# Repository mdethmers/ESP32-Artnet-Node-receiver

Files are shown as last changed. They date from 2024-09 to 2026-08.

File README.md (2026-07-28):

# ESP32-Artnet-Node-receiver

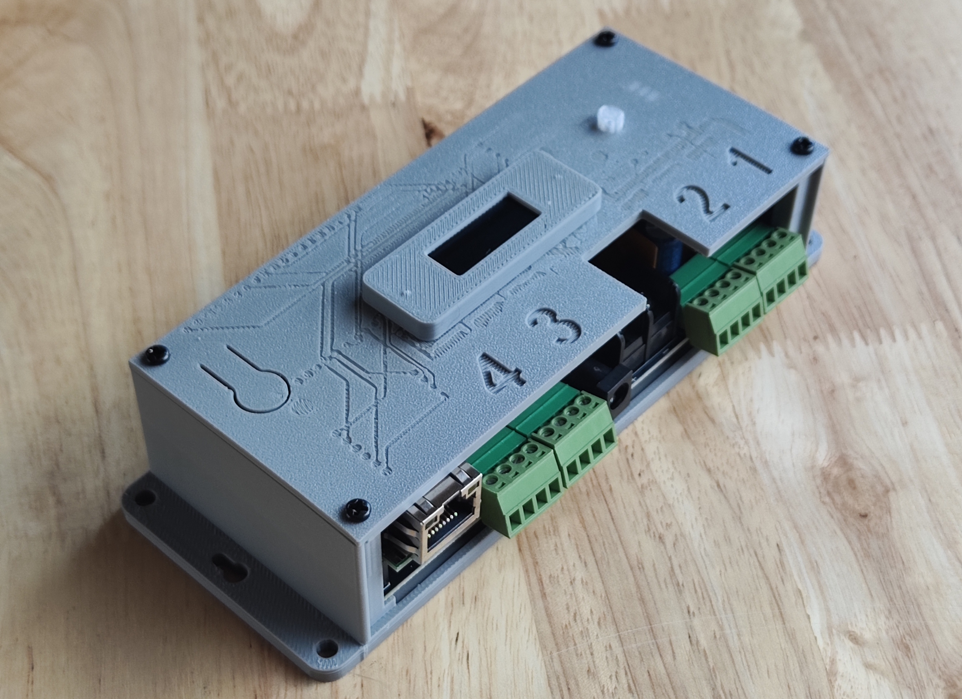
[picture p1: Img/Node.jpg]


This Artnet ESP32 LED controller is a high-performance, open-source solution for controlling addressable LEDs using Ethernet or Wi-Fi. This project allows you to control multiple LED strips using the Artnet protocol via an ESP32 microcontroller with a W5500 Ethernet module or ESP32-ETH01. The code includes a simple web server for configuration and control of the LED strips. For optimal performance, use the W5500 as the ETH01 suffers from performance issues. 

NOW FOR SALE: [https://www.etsy.com/nl/shop/LichtBit](https://lichtbit.etsy.com)

### Videos & Tutorials
Soldering Tutorial: https://www.youtube.com/watch?v=-qxbHJJCwbM

Node & Resolume Arena configuration: https://www.youtube.com/watch?v=1a7sWZTA7lg

## Features

- 4 Outputs, 16 Universes in Total: Supports up to 4 LED strips with 4 universes per output, enabling large-scale LED installations.
- Supports 3 (RGB), 4 (RGBW), and 5 (RGBAW) color order LEDs.
- Supports 3-wire LEDs (WS28xx) and 4-wire  SPI clock-based LEDs (APA102).
- Ethernet and Wi-Fi Support: Supports both wired and wireless Art-Net control for flexible connectivity.
- AP Mode for Debugging: Easily configure the device in standalone mode without needing an external network.
- Static IP option for permanent installations.
- Physical button for Mode switching between artnet, static IP, RGB test and static color.
- Over-The-Air (OTA) updates to update your node with different versions easily.
- Configure the number of LEDs, outputs, start universe, and node name via a web interface.
- High Frame Rates: Over 40 FPS, depending on the software used.
- Reliable Performance: Boasts 99%+ reliability with less than 1% dropped frames.
- 128x32 OLED Display Support: Provides real-time status updates and configuration feedback.
- Status RGB LED: Indicates device status for easy debugging and monitoring.
- **RGB Test Cycle**: Quickly test LED outputs with built-in cycling modes.
- Fully Open-Source: Includes PCB design and BOM, allowing users to build their own cost-effective controllers.

## PCB Design
This is the ongoing PCB design, using 12v-to-5v step-down converters, car fuses for protection and screw terminals for easy connections. 
Project: https://oshwlab.com/matthijsdethmers/artnetnode-esp32
EasyEDA Editor: https://easyeda.com/editor#project_id=86fd5b1121594bfa85fd2c5eed017e20

## Hardware Requirements

- ESP32-Wroom-Dev1 (or ESP32-ETH01 microcontroller)
- W5500 Ethernet module
- LED strips compatible with I2SClockless LED driver (Tested on WS2811, WS2812(B), WS2815)
- 128x32 OLED Display (Optional for visual feedback)
- WS2812 RGB Status LED (Optional for status indication)
- 12v/5v Power Supply

**Important!** Only a few ESP32's are supported! Check the WebServer_ESP32_W5500 for supported Boards when using the W5500.

## Node Pinout
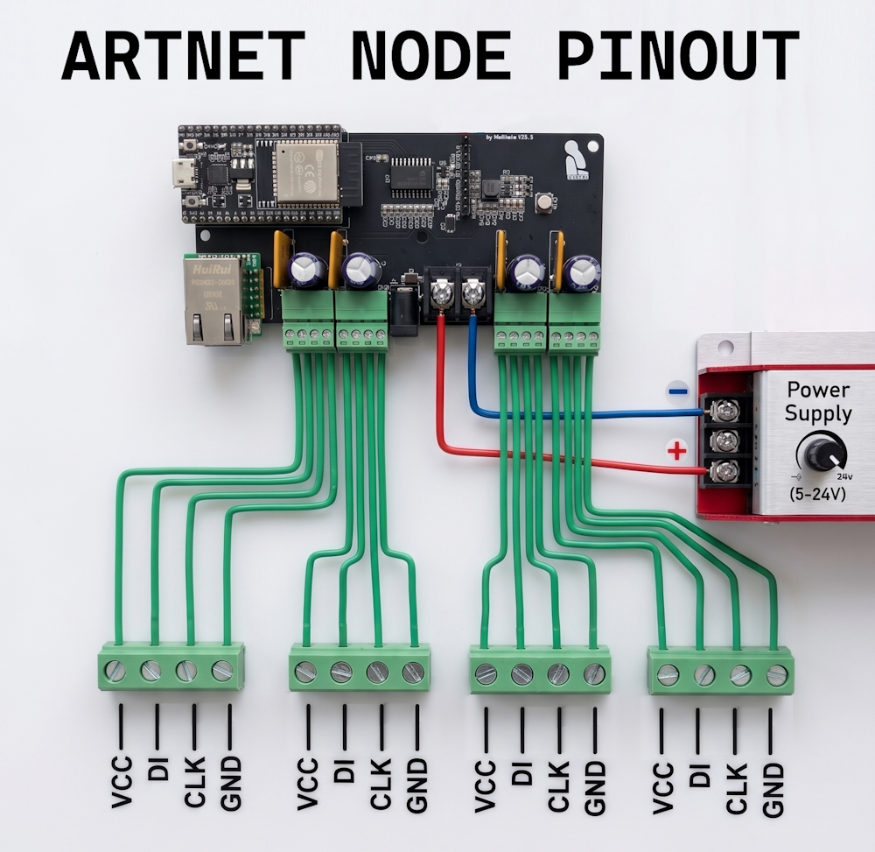
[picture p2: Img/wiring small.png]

  
## Software Requirements

- Arduino IDE with ESP32 support
- Espressif ESP32 board manager library
  - Use https://espressif.github.io/arduino-esp32/package_esp32_index.json
  - Version 2.0.17 or lower, otherwise compilation errors arise
- Libraries:
  - **Preferences** https://www.arduino.cc/reference/en/libraries/preferences/
  - **WebServer_ESP32_W5500** https://github.com/khoih-prog/WebServer_ESP32_W5500
  - **I2SClocklessLedDriver** https://github.com/hpwit/I2SClocklessLedDriver
  - **FORKED artnetESP32V2** https://github.com/mdethmers/artnetesp32v2
  - WebServer.h (For Wi-Fi and web interface support)
  - Adafruit_NeoPixel.h (For addressable LED control)
  - SPI.h, Wire.h (Built-in libraries for communication)
  - Adafruit_GFX.h (Graphics library for OLED)
  - Adafruit_SSD1306.h (OLED display driver)
  - Update.h (OTA updates)
 
## Supported LED ICs
All LEDs based on the wsXXXX and clocked LED series are supported. These can be 3, 4, or 5 channel LEDs. These include, but are not limited to:
  - WS2805, WS2811, WS2812, WS2813, WS2814, WS2815 (Tested)
  - APA102, SK6812 SPI-based LEDs (Tested)
  - SK6812, SK6812W, SK6812-mini (Not tested)
  - GS8208, TM1814, TM1829, UCS8904, UCS8903, FW1906 (Not tested)

## WLED
Check this [youtube video](https://www.youtube.com/watch?v=f3e7oMOB8D4) on how to install WLED!

This controller also supports the WLED software (WIFI ONLY!), supporting Artnet, DMX, and Standalone animations. When using multiple nodes, these can sync over WIFI in standalone mode. Install WLED through the [Web Installer](https://install.wled.me/) (plain version!).
In the WLED folder, you can find a [WLED config file](WLED/wled_cfg.json) that works with the controller, which you can use to receive the correct pin settings. Upload these in the security and update pagae > Restore configuration. This config file is set to 680 LEDs per pin, using a 10A power supply, and with WS2814/SK6912 type leds. CHANGE THESE ACCORDING TO YOUR OWN SETUP!

The W5500 Ethernet module and OLED screen can work with WLED:
- W5500 capable version of WLED is available here and should work (Not tested): https://github.com/stcalica/WLED-W500
- 128x32 OLED 4-line display mod available as well (Not tested): https://mm.kno.wled.ge/usermods/4LineDisplay/#installation_1

### WLED ARTNET / sACN (E1.31)
To get Artnet to work on your WLED install, go to SYNC settings and set your network DMX input to Artnet or sACN (E1.31), and DMX mode to Multi-RGB. Make sure to reboot. 
In LED preferences, set the number of LEDs to the number of universes you need (Eg. 340 for 2 universes per output, maximum I got working was 510 leds / 9 universes). Set resolume to send the number of universes equal to # outputs * # of universes per output. 
# Configuration

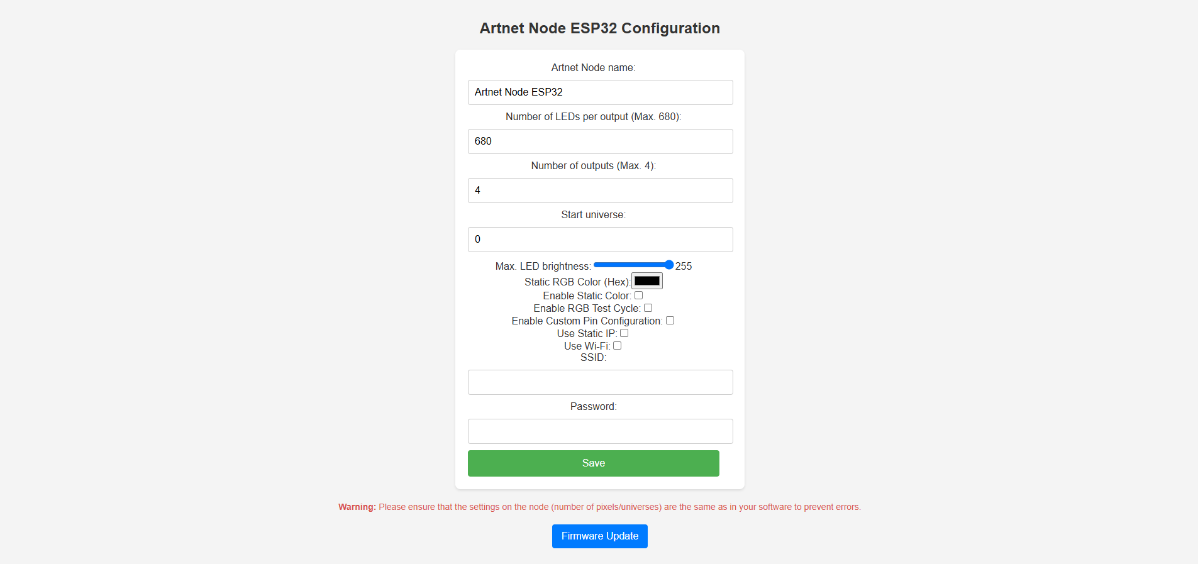
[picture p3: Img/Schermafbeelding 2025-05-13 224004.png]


## Access the Web Interface:
- After uploading the code, connect your ESP32 to a network using the W5500 Ethernet module.
- Set core debug level to "info" for extra information on performance
- Find the IP address assigned to the ESP32 and open it in a web browser.
  - To find the IP address easily, use Resolume's advanced output. It will autodetect the Artnet node.
 
## Mode switching with the Boot button
The code allows you to use the boot button to switch between Ethernet, Wifi, AP, RGB Test cycle, and a static colour. In some of the modes, a long press allows you to change more settings by single pressing. Exit by long-pressing again.  
- Ethernet > Long press > Switch between static IP / DHCP (WORKING!)
- Wifi > Long press > Switch between static IP / DHCP (WORKING!)
- RGB Test cycle > Long press > Switch to other test pattern (Not implemented yet)
- Static colour > Long press > Switch between 10 different colours (WORKING!)

Change this code with your own colours before compiling. 
```
const String presetColors[PRESET_COLORS_COUNT] = {
  "#FF0000", // Red
  "#00FF00", // Green  
  "#0000FF", // Blue
  "#FFFF00", // Yellow
  "#FF00FF", // Magenta
  "#00FFFF", // Cyan
  "#FFFFFF", // White
  "#FF8000", // Orange
  "#8000FF", // Purple
  "#000000"  // Black/Off
};
```
 
## OTA updates
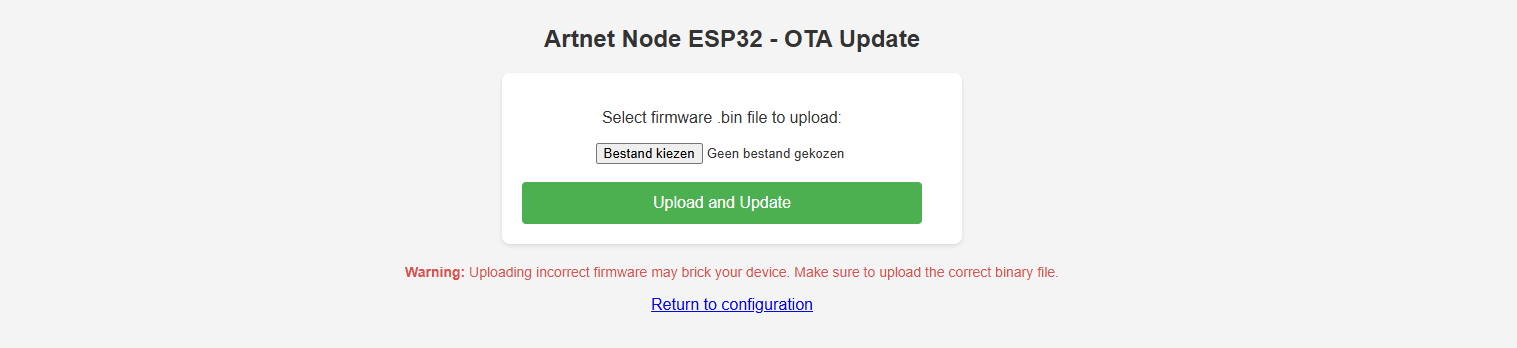
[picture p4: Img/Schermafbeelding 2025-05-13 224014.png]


Upload the BIN file to your Node to have OTA updates. Easy when your node is in a hard to reach or remote place!

## Access the AP mode:
- After 30 seconds without any Ethernet response, an AP mode will automatically launch
- You can use this to connect to the Node and set up settings or a Wifi connection. 

## Configure the LED Controller:
Important! Be sure that the Universes/outputs/leds always match what you output. A mismatch can result in a black output. 

## Pin/Setting/Config info
- Default led strip pins are 12, 14, 27, 26 (more outputs can be added if necessary. Change config accordingly).
- Default status led is set to pin 16.
- SPI-based LED clock line can run from Pin 17. Never versions of the board have this pin connected in the connector. 
- Level shifter OE is set to pin 25 and should be set LOW
- Pin 16/17 can be reprogrammed for new functionality/adding more outputs. (They are connected to the 5v level shifter). 
- I2C pins for OLED are set to pins 21 and 22.
- The default timeout is set to 30 seconds.
- There is a 5V switch Where the 12v regulator sits. Use this if you power the node with 5V instead of 12V! The esp and other logic will be powered from the 5v power supply instead of the 12v to 5v regulator.

To enable outputs, the level shifter should have its OE set to low. OE is connected to IO25, and can be set during setup like this; 
```
void setup() {
  Serial.begin(115200);

  pinMode(ShifterPin, OUTPUT);
  digitalWrite(ShifterPin, LOW);
```

### A note on direct Ethernet connection between Node and PC
Sadly, the W5500 does not support Auto-MDI/MDIX, which means you need a crossover cable whenever you want to connect directly from your PC to the Node with an Ethernet cable!

# Basic resolume setup example
To get you up and running with your node, I provide a basic setup example for Resolume. Other software will work similarly.
1. Connect your node to a router (DHCP) or switch (Static IP) through Ethernet, wifi, or AP mode (192.168.4.1).
2. Once your node is successfully connected to your network, navigate to the configuration page (192.168.1.xxx) and set the Node's Name, Number of outputs, and MAXIMUM Leds you connect to your output.
3. Optional) Enable the RGB test cycle or Static color to test if all outputs and LEDs behave as expected.
4. In Resolume, set the correct network adapter in Preferences>DMX.
5. In Resolume's advanced output, add a new Lumiverse and add the LED strips.
6. In Resolume's advanced output, set the IP address.
7. The node supports 4 universes (680 LEDS) per output. If you need all 16 universes (680 leds per output), add 4 Lumiverse outputs and set the right universes per output. For output 1 that is start universe 0, For output 2 that is start universe 4, For output 3 that is start universe 8, For output 4 that is start universe 12. Change this to the number of universes per output that you need.
8. Your strips should now light up!

## Open-Source Contributions
This project is fully open-source! Feel free to contribute improvements, share your builds, and collaborate with the community.

##License
This project is released under the MIT License. You are free to use, modify, and distribute it with proper attribution.

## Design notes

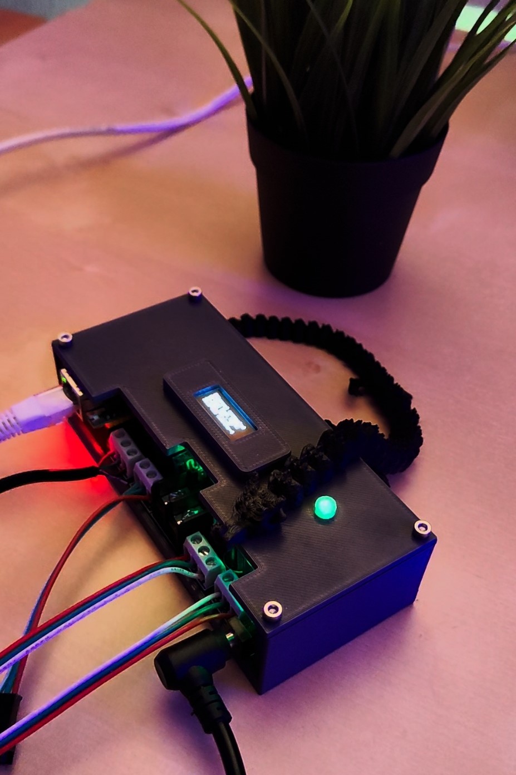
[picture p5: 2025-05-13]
Img/Screenshot_2025-04-18-11-17-45-936_com.miui.mediaviewer[1].jpg

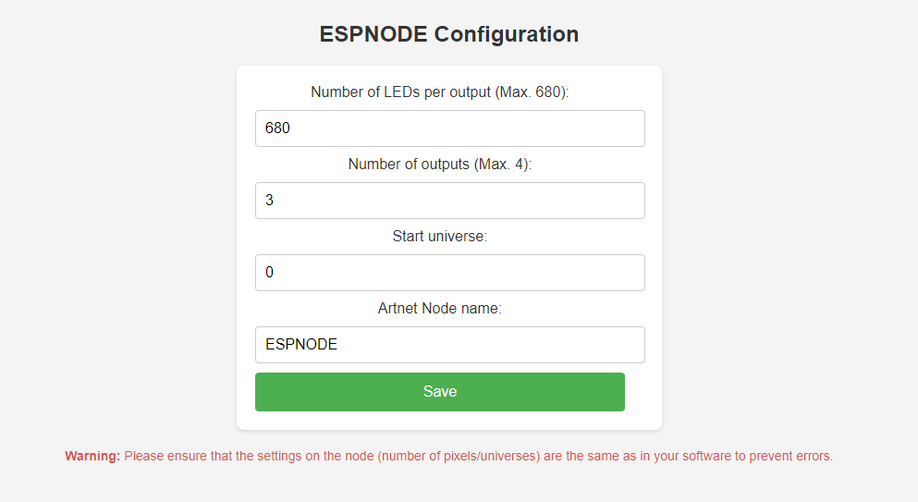
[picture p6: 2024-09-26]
Img/Schermafbeelding 2024-09-26 162838.png

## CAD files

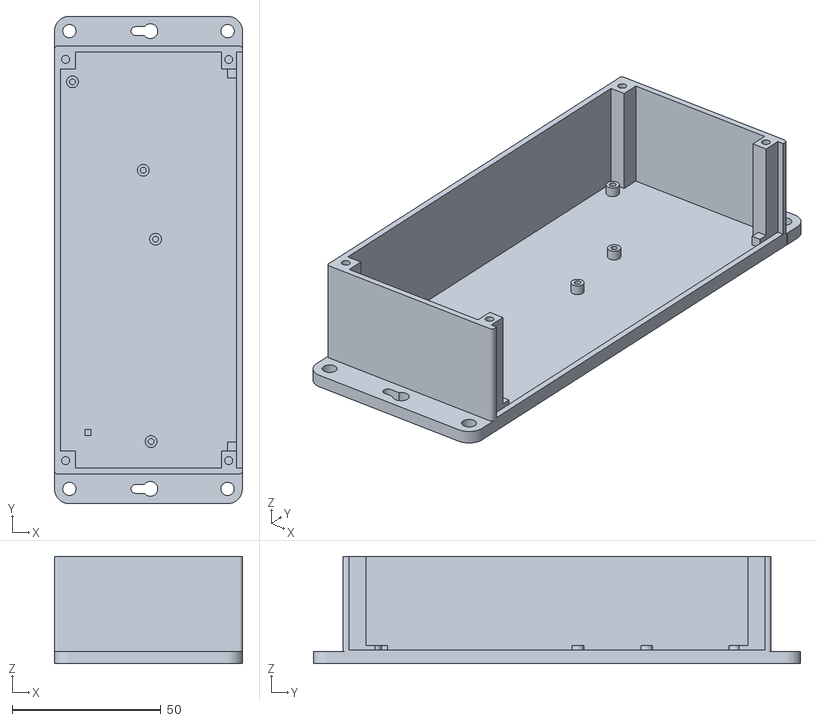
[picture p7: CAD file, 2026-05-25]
3D Print Files/artnetnode shell V2.stl
63.2 x 164.0 x 36.0

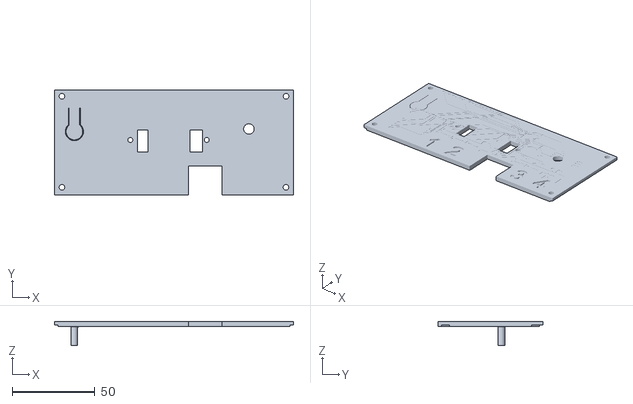
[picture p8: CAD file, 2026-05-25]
3D Print Files/Artnet ART top V3 - boot.stl
144.0 x 63.2 x 14.5

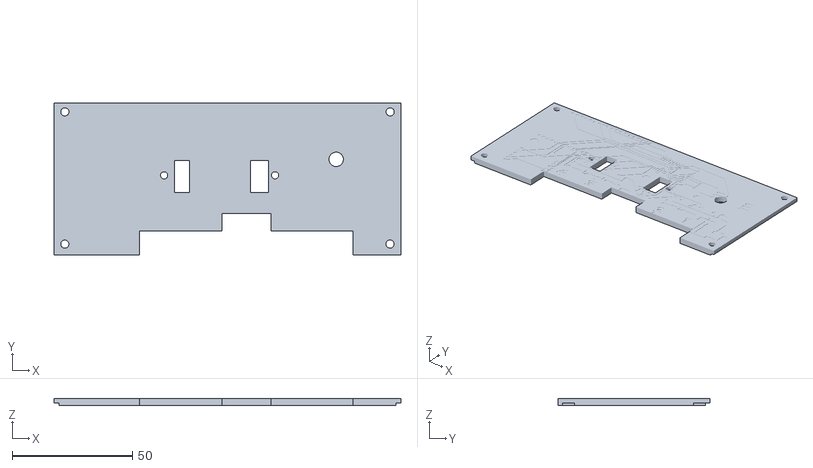
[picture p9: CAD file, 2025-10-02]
3D Print Files/Artnet ART top V1.stl
144.0 x 63.2 x 3.00

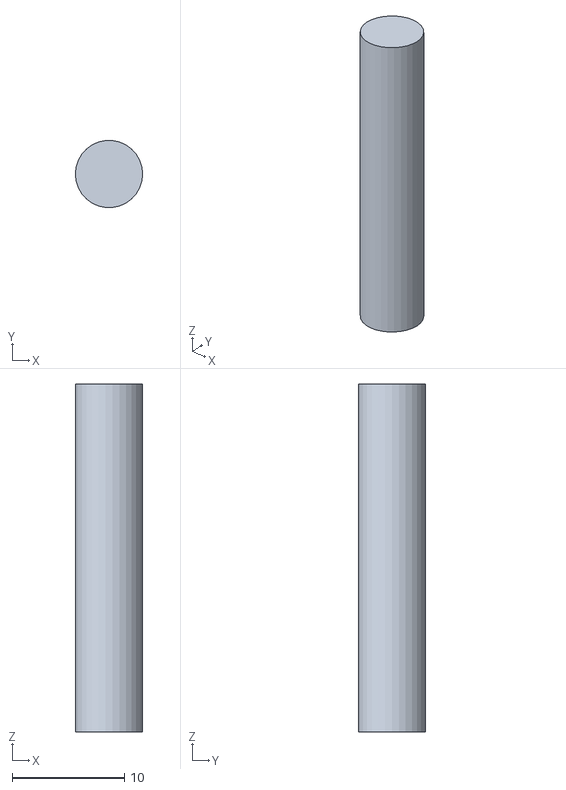
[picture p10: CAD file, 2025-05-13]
3D Print Files/artnetnode shell led.stl
6.00 x 5.97 x 31.0

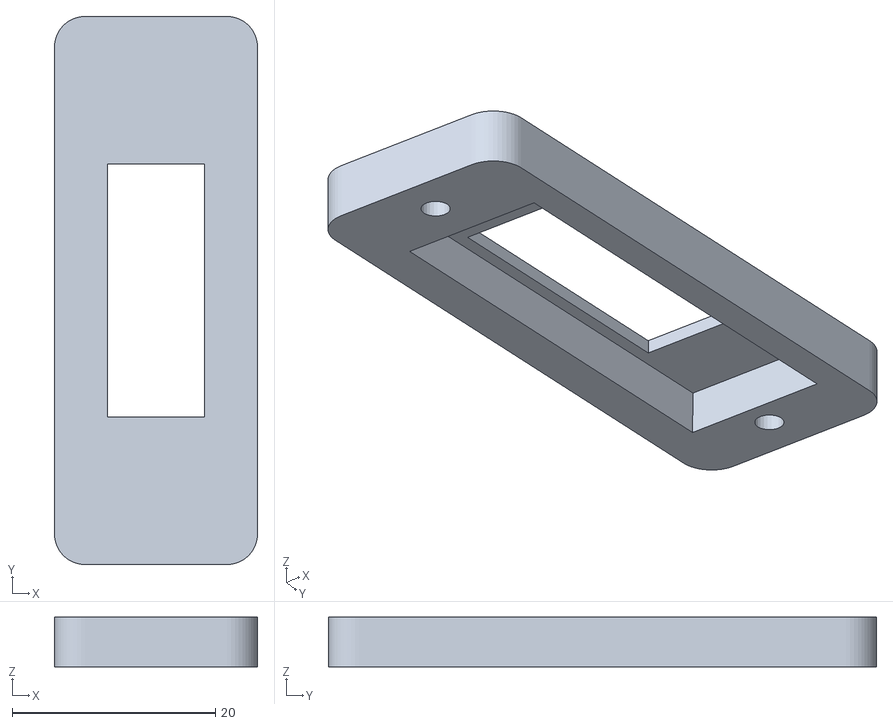
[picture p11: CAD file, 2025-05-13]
3D Print Files/artnetnode oled v10.stl
20.0 x 54.0 x 4.90

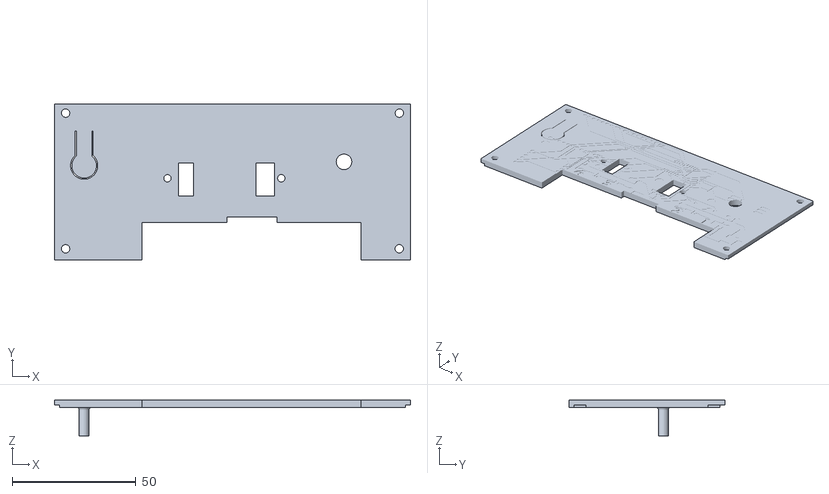
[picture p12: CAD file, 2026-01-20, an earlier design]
3D Print Files/Artnet ART top V2 - boot.stl
144.0 x 63.2 x 14.5

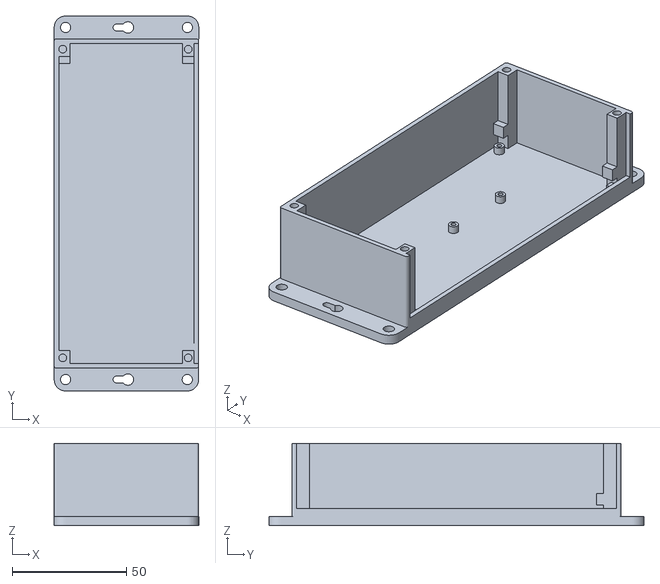
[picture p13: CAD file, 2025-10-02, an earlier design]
3D Print Files/artnetnode shell.stl
63.2 x 164.0 x 36.0

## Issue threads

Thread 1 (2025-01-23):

COLOR_GRB  should be COLOR_ORDER_GBR

koppa, 2025-01-23:
COLOR_GRB  should be COLOR_ORDER_GBR
see https://github.com/hpwit/I2SClocklessLedDriver/blob/main/src/I2SClocklessLedDriver.h#L71

mdethmers, 2025-01-23:
Can you share more info n this? I just updated my libraries to recreate the issue but it still compiles okay even with the COLOR_GRB definition.

koppa, 2025-01-26:
The wrong definition behaves the same, because in case of no definition of COLOR_ORDER_XXX the fallback is driving the leds in GRB configuration. (else case in line 112)

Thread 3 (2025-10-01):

Question - definition of led for matrix 16x16

Pampersfr, 2025-10-01:
hi
thanks a lot for your good work of this project !
i try to use it with 4 matrix led 16x16 (1024 leds of total)

what confirguration you suggest me ?
1 pin with 1024 leds (the 4 matrix plug together)
4 pin (so 4 output?) with 256 led for each output?
or other ?

thanks a lot for your help
regards

mdethmers, 2025-10-01:
Hey! If you are not comfortable to tweak the settings yourself, ity should be possible to send 256 pixels (2 universes) to the 4 different outputs. However, you could also set the leds to 1024 (6 universes) for 1 output only, but the FPS will be lower (~33). However, any configuration works really. 1/3, 2/2, 3/1, 1/1/1/1 etc.

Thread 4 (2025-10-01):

Unable to receive DMX artnet

Pampersfr, 2025-10-01:
Hello

i try to use your code with just one WS2812b leds Matrix 16x16 (256 leds)
i use arduino IDE (v2.3.6 on windows 10 - 64bits) to compile with this version of library 👍 :

```
#include <Preferences.h> //v2.1.0
#include <WebServer_ESP32_W5500.h> //v1.5.3
#include <WebServer.h> //v2.0.17 with ESP32 Board
#include "I2SClocklessLedDriver.h" // Manually install https://github.com/hpwit/I2SClocklessLedDriver/tree/main/src v1.3
#include "Arduino.h" //v2.0.17 with ESP32 Board
#include "artnetESP32V2.h" // Manually install https://github.com/hpwit/artnetesp32v2/tree/main/src v1.5
#include <Adafruit_NeoPixel.h> //v1.15.1
#include <SPI.h> //v2.0.17 with ESP32 Board
#include <Wire.h> //v2.0.17 with ESP32 Board
#include <Adafruit_GFX.h> //v1.12.3
#include <Adafruit_SSD1306.h> //v2.5.15
#include <Update.h> //v2.0.17 with ESP32 Board
```

for parameters i have :
```
// LED configuration
#define NUM_LEDS_PER_STRIP 256
#define NUMSTRIPS 1          
#define NB_CHANNEL_PER_LED 3
#define UNIVERSE_SIZE_IN_CHANNEL 510
#define COLOR_RBG            
const int DEFAULT_PINS[NUMSTRIPS] = {13};
```

No status led and no OLED screen for the moment.
Connexion by wifi 10.3.141.xxx with router

compilation ok, test led on beginning ok, connection wifi ok, listing artnet :
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

when i try to do a telnet on 6454 :
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

when i try with ledFx (https://github.com/LedFx/LedFx) with my pc connected on same wifi router (with ip 10.3.141.95)  with artnet device unable to connect to my node 10.3.141.110
i forget something ?

thanks a lot
regards

mdethmers, 2025-10-01:
Hey! Im not seeing anything wrong right now, but I dont know what the rest of your code looks like. Personally I use the esp32 by espressif version 2.0.17. Please confirm if you have this as well, but I guess you do as the code compiles fine. You can set the core debug level to "info" to see additional information.

If succesfully connected to ethernet, I receive the following message;

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

Please let me know if you have further questions :)

Pampersfr, 2025-10-02:
hi
i confirme i use 2.0.17 esp32 expressif library
the full code :
```
/*
 * https://github.com/mdethmers/ESP32-Artnet-Node-receiver/tree/main?tab=readme-ov-file
 * ArtNet LED Controller for ESP32
 * Controls multiple LED strips via ArtNet protocol over Ethernet or WiFi
 * Provides web interface for configuration and supports static colors and test patterns
 */

// Feature configuration
#define DEBUG_ETHERNET_WEBSERVER_PORT Serial
#define _ETHERNET_WEBSERVER_LOGLEVEL_ 1  // Reduced log level for less overhead
#define UNIQUE_SUBARTNET

// LED configuration
#define NUM_LEDS_PER_STRIP 256        // Maximum number of LEDs per strip
#define NUMSTRIPS 1                   // Maximum number of LED strips
#define NB_CHANNEL_PER_LED 3          // Number of channels per LED (3 for RGB, 4 for RGBW)
#define UNIVERSE_SIZE_IN_CHANNEL 510  // Size of a universe (170 pixels * 3 channels)
#define COLOR_RBG                     // Define color order (Green-Red-Blue)

// Hardware configuration
#define STATUS_LED_PIN 12
#define SCREEN_WIDTH 128
#define SCREEN_HEIGHT 32
#define OLED_RESET 4
#define SCREEN_ADDRESS 0x3C

// Include necessary libraries
#include <Preferences.h> //v2.1.0
#include <WebServer_ESP32_W5500.h> //v1.5.3
#include <WebServer.h> //v2.0.17 with ESP32 Board
#include "I2SClocklessLedDriver.h" // Manually install https://github.com/hpwit/I2SClocklessLedDriver/tree/main/src v1.3
#include "Arduino.h" //v2.0.17 with ESP32 Board
#include "artnetESP32V2.h" // Manually install https://github.com/hpwit/artnetesp32v2/tree/main/src v1.5
#include <Adafruit_NeoPixel.h> //v1.15.1
#include <SPI.h> //v2.0.17 with ESP32 Board
#include <Wire.h> //v2.0.17 with ESP32 Board
#include <Adafruit_GFX.h> //v1.12.3
#include <Adafruit_SSD1306.h> //v2.5.15
#include <Update.h> //v2.0.17 with ESP32 Board

// Default pin configuration
//const int DEFAULT_PINS[NUMSTRIPS] = {12, 14, 27, 26};
const int DEFAULT_PINS[NUMSTRIPS] = {13};

// Forward declarations for functions
void setupWiFi();
void setupEthernet();
void startAPMode();
void cycleLEDs();
void setStatusLED(uint8_t r, uint8_t g, uint8_t b);
void applyStaticColor();
void loadSettings();
void saveSettings();
void handleRoot();
void handleConfig();
void resetToDefaultPins();
void updateStripPins();
void displayStatus(const String& line1, const String& line2 = "", const String& line3 = "", const String& line4 = "");
void displayConnectionStatus(const String& type, int remainingTime = -1);
void handleOTAUpdate();
void handleDoUpdate();
void printOTAProgress(size_t prg, size_t sz);

// Configuration structure
struct Settings {
  int numLedsPerOutput = 256;
  int numOutputs = 1;
  int startUniverse = 0;
  //int pins[NUMSTRIPS] = {12, 14, 27, 26};
  int pins[NUMSTRIPS] = {13};
  int ledBrightness = 25;
  String nodeName = "ESLI-Artnet_Node01";
  String ssid = "RaspAP-ESLI";
  String password = "xxxxxxx";
  bool useWiFi = true;
  String staticColor = "#009900";
  bool enStatColor = true;
  bool enableCustomPins = false;
  bool ledCycleEnabled = false;
  bool useStaticIP = true;
  String staticIP = "10.3.141.110";
  String gateway = "10.3.141.1";
  String subnet = "255.255.255.0";
};

// Runtime state
struct State {
  bool isAPMode = false;
  bool ledCycleEnabled = false;
  bool isStaticColorSet = false;
  uint8_t currentColor = 0;  // 0 = Red, 1 = Green, 2 = Blue
  unsigned long lastUpdate = 0;
  unsigned long startAttemptTime = 0;
  bool ledState = false;
};

// Constants
const unsigned long CONNECTION_TIMEOUT = 30000; // 30 seconds timeout
const unsigned long CYCLE_DELAY = 1000;         // Change color every 1 second

// Global objects
Adafruit_SSD1306 display(SCREEN_WIDTH, SCREEN_HEIGHT, &Wire, OLED_RESET);
Adafruit_NeoPixel StatusLed(1, STATUS_LED_PIN, NEO_GRB + NEO_KHZ800);
WebServer server(80);
Preferences preferences;
artnetESP32V2 artnet = artnetESP32V2();
I2SClocklessLedDriver driver;

// LED storage
uint8_t ledData[NB_CHANNEL_PER_LED * NUMSTRIPS * NUM_LEDS_PER_STRIP];

// Settings and state
Settings settings;
State state;

// LED strip objects
Adafruit_NeoPixel strips[NUMSTRIPS] = {
  Adafruit_NeoPixel(NUM_LEDS_PER_STRIP, DEFAULT_PINS[0], NEO_BRG + NEO_KHZ800),
//  Adafruit_NeoPixel(NUM_LEDS_PER_STRIP, DEFAULT_PINS[1], NEO_BRG + NEO_KHZ800),
//  Adafruit_NeoPixel(NUM_LEDS_PER_STRIP, DEFAULT_PINS[2], NEO_BRG + NEO_KHZ800),
//  Adafruit_NeoPixel(NUM_LEDS_PER_STRIP, DEFAULT_PINS[3], NEO_BRG + NEO_KHZ800)
};

// ArtNet callback function
void displayfunction(void *param) {
  subArtnet *subartnet = (subArtnet *)param;
  driver.showPixels(NO_WAIT, subartnet->data);
}

/**
 * Main setup function
 */
void setup() {
  Serial.begin(115200);

  // Initialize status LED
  StatusLed.begin();
  setStatusLED(255, 255, 0);  // Yellow during initialization

  // Initialize OLED display
  if(!display.begin(SSD1306_SWITCHCAPVCC, SCREEN_ADDRESS)) {
    Serial.println(F("SSD1306 allocation failed"));
  }
  displayStatus("Initializing...");

  // Load settings from preferences
  loadSettings();

  // Update strip pins based on loaded settings
  updateStripPins();

  // Initialize LED driver
  driver.initled(ledData, settings.pins, NUMSTRIPS, NUM_LEDS_PER_STRIP);
  driver.setBrightness(settings.ledBrightness);

  // Initialize networking
  state.startAttemptTime = millis();
  if (settings.useWiFi) {
    setupWiFi();
  } else {
    setupEthernet();
  }

  // If not in AP mode, set up ArtNet
  if (!state.isAPMode) {
    IPAddress activeIP = settings.useWiFi ? WiFi.localIP() : ETH.localIP();

    // Update display with connection info
    String ipStr = activeIP.toString();
    String ledsInfo = "LEDs:" + String(settings.numLedsPerOutput) +
                      " Out:" + String(settings.numOutputs);
    displayStatus(settings.nodeName, ipStr, ledsInfo);

    // Initialize ArtNet
    artnet.addSubArtnet(
      settings.startUniverse,
      settings.numLedsPerOutput * settings.numOutputs * NB_CHANNEL_PER_LED,
      UNIVERSE_SIZE_IN_CHANNEL,
      &displayfunction
    );
    artnet.setNodeName(settings.nodeName);

    if (artnet.listen(activeIP, 6454)) {
      Serial.print("Artnet Listening on IP: ");
      Serial.println(activeIP);
    }
  }
}

/**
 * Main loop function
 */
void loop() {
  // Handle web server requests
  server.handleClient();

  // Check network status
  if (!state.isAPMode) {
    bool networkDisconnected = (settings.useWiFi && WiFi.status() != WL_CONNECTED) ||
                             (!settings.useWiFi && (ETH.localIP() == INADDR_NONE));

    if (networkDisconnected) {
      Serial.println("Network disconnected, restarting AP mode...");
      startAPMode();
    }
  }

  // Handle LED test cycle or static color
  if (settings.enStatColor && !state.isStaticColorSet) {
    applyStaticColor();
    state.isStaticColorSet = true;
  } else if (settings.ledCycleEnabled) {
    cycleLEDs();
    state.isStaticColorSet = false;
  } else if (!settings.enStatColor) {
    state.isStaticColorSet = false;
  }
}

/**
 * Update all LED strip pins according to settings
 */
void updateStripPins() {
  for (int i = 0; i < NUMSTRIPS; i++) {
    if (strips[i].getPin() != settings.pins[i]) {
      Serial.printf("Strip %d pin changed from %d to %d\n",
                    i, strips[i].getPin(), settings.pins[i]);

      strips[i].setPin(settings.pins[i]);
      strips[i].begin();
    }
  }
}

/**
 * Load settings from preferences
 */
void loadSettings() {
  preferences.begin("esp32config", true);

  settings.numLedsPerOutput = preferences.getInt("numledsoutput", settings.numLedsPerOutput);
  settings.numOutputs = preferences.getInt("numoutput", settings.numOutputs);
  settings.startUniverse = preferences.getInt("startuniverse", settings.startUniverse);
  settings.nodeName = preferences.getString("nodename", settings.nodeName);
  settings.ledBrightness = preferences.getInt("ledbrightness", settings.ledBrightness);
  settings.ssid = preferences.getString("ssid", settings.ssid);
  settings.password = preferences.getString("password", settings.password);
  settings.useWiFi = preferences.getBool("useWiFi", settings.useWiFi);
  settings.staticColor = preferences.getString("staticColor", settings.staticColor);
  settings.enStatColor = preferences.getBool("enStatColor", settings.enStatColor);
  settings.enableCustomPins = preferences.getBool("enCustomPins", settings.enableCustomPins);
  settings.ledCycleEnabled = preferences.getBool("ledCycleEnabled", settings.ledCycleEnabled);
  settings.useStaticIP = preferences.getBool("useStaticIP", settings.useStaticIP);
  settings.staticIP = preferences.getString("staticIP", settings.staticIP);
  settings.gateway = preferences.getString("gateway", settings.gateway);
  settings.subnet = preferences.getString("subnet", settings.subnet);

  // Load pins
  for (int i = 0; i < NUMSTRIPS; i++) {
    char pinKey[10];
    sprintf(pinKey, "pin%d", i);
    settings.pins[i] = preferences.getInt(pinKey, DEFAULT_PINS[i]);
  }

  // If custom pins not enabled, use default pins
  if (!settings.enableCustomPins) {
    for (int i = 0; i < NUMSTRIPS; i++) {
      settings.pins[i] = DEFAULT_PINS[i];
    }
  }

  preferences.end();
}

/**
 * Reset pins to default values
 */
void resetToDefaultPins() {
  for (int i = 0; i < NUMSTRIPS; i++) {
    settings.pins[i] = DEFAULT_PINS[i];
  }
}

/**
 * Save settings to preferences
 */
void saveSettings() {
  preferences.begin("esp32config", false);
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

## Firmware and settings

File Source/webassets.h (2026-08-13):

#ifndef WEBASSETS_H
#define WEBASSETS_H

// Stylesheet and script for the configuration UI, served from /style.css and
// /app.js. They live in a header rather than the sketch because the Arduino
// builder scans .ino files with ctags to generate prototypes, and ctags does
// not understand C++11 raw string literals — it reads the JavaScript inside
// them as C++ and emits prototypes for it, which then fail to compile.

#define ASSET_VER "2"

// Colours follow the node's own signal language: amber is anything you can act
// on (the status LED and a venue worklight are both amber), green is live,
// blue is AP mode, red is trouble. Numbers are always monospace and tabular so
// universes and addresses line up the way they do on a patch sheet.
const char CSS_STYLES[] PROGMEM = R"css(
:root{
  --canvas:#eceff3; --panel:#fff; --sunk:#f4f6f9;
  --ink:#141821; --muted:#5b6472; --line:#d8dde5;
  --accent:#9c580c; --lit:#f0a73c; --lit-ink:#2a1a05;
  --live:#2c8f4f; --warn:#bf3a2e; --ap:#3767cf;
  --shadow:0 1px 2px rgba(18,22,30,.07),0 8px 22px rgba(18,22,30,.05);
  --f-ui:-apple-system,BlinkMacSystemFont,"Segoe UI",Roboto,"Helvetica Neue",Arial,sans-serif;
  --f-mono:ui-monospace,"Cascadia Mono",SFMono-Regular,"SF Mono",Consolas,"Liberation Mono",monospace;
}
:root[data-theme=dark]{
  --canvas:#101319; --panel:#191d25; --sunk:#20242e;
  --ink:#e7eaf0; --muted:#8b94a3; --line:#2b313c;
  --accent:#f0a73c; --lit:#f0a73c; --lit-ink:#1a1206;
  --live:#4ed489; --warn:#f2786e; --ap:#7ba6ff;
  --shadow:0 1px 2px rgba(0,0,0,.45);
}
@media (prefers-color-scheme:dark){:root:not([data-theme=light]){
  --canvas:#101319; --panel:#191d25; --sunk:#20242e;
  --ink:#e7eaf0; --muted:#8b94a3; --line:#2b313c;
  --accent:#f0a73c; --lit:#f0a73c; --lit-ink:#1a1206;
  --live:#4ed489; --warn:#f2786e; --ap:#7ba6ff;
  --shadow:0 1px 2px rgba(0,0,0,.45);
}}
*,*::before,*::after{box-sizing:border-box}
[hidden]{display:none!important}
html{-webkit-text-size-adjust:100%}
body{margin:0;padding:0 15px 36px;background:var(--canvas);color:var(--ink);
  font:400 15px/1.5 var(--f-ui);-webkit-font-smoothing:antialiased}
.shell{max-width:720px;margin:0 auto}
:focus-visible{outline:2px solid var(--lit);outline-offset:2px;border-radius:4px}

/* Masthead: who am I, where am I, what am I speaking */
.masthead{display:flex;align-items:flex-start;gap:12px;padding:26px 2px 18px}
.masthead .id{flex:1 1 auto;min-width:0}
h1{margin:0;font:700 clamp(21px,5vw,27px)/1.15 var(--f-ui);letter-spacing:-.015em;
  word-break:break-word}
.readout{margin:6px 0 0;font:400 13px/1.6 var(--f-mono);color:var(--muted)}
.dot{flex:none;width:9px;height:9px;margin-top:11px;border-radius:50%;background:var(--live)}
.dot.ap{background:var(--ap)}

/* Panels read like rack units: silkscreened legend, then controls */
.panel{margin:0 0 14px;background:var(--panel);border:1px solid var(--line);
  border-radius:10px;box-shadow:var(--shadow)}
.legend{position:relative;display:flex;align-items:center;gap:9px;padding:13px 16px;
  border-bottom:1px solid var(--line);font:600 11px/1 var(--f-ui);
  letter-spacing:.13em;text-transform:uppercase;color:var(--muted)}
.foot{margin:0;padding:12px 16px;border-top:1px solid var(--line);
  font:400 12.5px/1.5 var(--f-ui);color:var(--muted)}

/* min-height keeps the rhythm even: a toggle or slider row is shorter than a
   text-input row, and without it the panels read as ragged. */
.row{position:relative;display:grid;grid-template-columns:1fr 1.1fr;gap:9px 18px;
  align-items:center;min-height:64px;padding:13px 16px;border-bottom:1px solid var(--line)}
.row:last-child,.panel>:last-child>.row:last-child{border-bottom:0}
.row:hover,.row:focus-within{z-index:4}
.lbl{display:flex;align-items:center;gap:6px;min-width:0;font-weight:500}
.hint{grid-column:1/-1;margin:-1px 0 0;font:400 12.5px/1.5 var(--f-ui);color:var(--muted)}
@media (max-width:560px){.row{grid-template-columns:1fr}}

input[type=text],input[type=password],input[type=number]{width:100%;padding:9px 11px;
  border:1px solid var(--line);border-radius:7px;background:var(--sunk);color:var(--ink);
  font:400 15px/1.35 var(--f-ui)}
input[type=number],.mono{font-family:var(--f-mono);font-variant-numeric:tabular-nums}
input::placeholder{color:var(--muted);opacity:.75}
input[type=file]{width:100%;padding:8px;border:1px dashed var(--line);border-radius:7px;
  background:var(--sunk);color:var(--muted);font:400 13.5px var(--f-ui);cursor:pointer}
input[type=file]::file-selector-button{margin-right:10px;padding:7px 12px;border:0;
  border-radius:6px;background:var(--lit);color:var(--lit-ink);cursor:pointer;
  font:600 13px var(--f-ui)}
input[type=color]{width:100%;max-width:130px;height:38px;padding:3px;
  border:1px solid var(--line);border-radius:7px;background:var(--sunk);cursor:pointer}
input[type=range]{width:100%;height:24px;accent-color:var(--lit)}
.meter{display:flex;align-items:center;gap:12px}
.meter output{flex:none;min-width:3.6em;text-align:right;
  font:600 14px var(--f-mono);font-variant-numeric:tabular-nums}
.meter output.wide{min-width:7.6em}

/* One segmented control for every either/or choice on the page */
.seg{display:flex;flex-wrap:wrap;gap:3px;padding:3px;background:var(--sunk);
  border:1px solid var(--line);border-radius:8px}
.seg input{position:absolute;width:1px;height:1px;margin:0;opacity:0}
.seg label{flex:1 1 auto;padding:7px 10px;border-radius:6px;text-align:center;
  cursor:pointer;white-space:nowrap;font:500 13.5px/1.25 var(--f-ui);color:var(--muted);
  -webkit-user-select:none;user-select:none}
.seg label:hover{color:var(--ink)}
.seg input:checked+label{background:var(--lit);color:var(--lit-ink);font-weight:600}
.seg input:focus-visible+label{outline:2px solid var(--lit);outline-offset:2px}

.sw{position:relative;display:inline-block;flex:none;width:42px;height:24px}
.sw input{position:absolute;z-index:2;width:100%;height:100%;margin:0;opacity:0;cursor:pointer}
.sw i{position:absolute;inset:0;border-radius:99px;background:var(--line);transition:background .15s}
.sw i::after{content:'';position:absolute;top:3px;left:3px;width:18px;height:18px;
  border-radius:50%;background:var(--panel);box-shadow:0 1px 2px rgba(0,0,0,.35);
  transition:transform .15s}
.sw input:checked+i{background:var(--lit)}
.sw input:checked+i::after{transform:translateX(18px)}
.sw input:focus-visible+i{outline:2px solid var(--lit);outline-offset:2px}
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

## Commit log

2024-09-26 Create ESP32-3x4Universe-Working
    Tested functional sketch of the esp32 pushing 3 pins with 4 universes each, enabling 680 pixels on each output with a total maximum of 2040 pixels on 1 device at 27~30FPS
2024-09-26 Update ESP32Wroom_Config-and-artnet.ino
    Confirmed working version, including working config through IP and storing of preferences locally.
2024-09-26 Update ESP32Wroom_Config-and-artnet.ino
    Updated Config page UI
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2024-11-25 Update ESP32-ETH01-Node
    Added wifi and AP mode. Updated UI to support Wifi mode.
2024-11-27 Update and rename ESP32Wroom_Config-and-artnet.ino to ESP32Wroom_W5500_Wifi_and_Ethernet
    Added a config meny option for wifi, as well as an AP mode when no connection is established
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2025-03-12 Update ESP32Wroom_W5500_Wifi_and_Ethernet
    Added support for a 128x32 OLED screen, added support for a ws2812-type status LED, added RGB test cycle toggle in web-ui for debugging
2025-03-12 Update ESP32Wroom_W5500_Wifi_and_Ethernet
    Added the right file with previously mentioned additions
2025-03-21 Update ESP32Wroom_W5500_Wifi_and_Ethernet
    Added static color, added correct Color order, and refactored code for easier readability.
2025-04-18 Update ESP32Wroom_W5500_Wifi_and_Ethernet
    Added a custom pin output option in the webUI
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2025-05-13 3D printed case files
    [artnetnode shell led.stl, artnetnode shell v10 oled.stl, artnetnode shell v10 shell.stl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]
2025-05-13 Rename artnetnode shell v10 top.stl to 3D Print Files/artnetnode shell top.stl
    [artnetnode shell top.stl]
2025-05-13 Rename artnetnode shell led.stl to 3D Print Files/artnetnode shell led.stl
    [artnetnode shell led.stl]
2025-05-13 Rename artnetnode shell v10 oled.stl to 3D Print Files/artnetnode shell oled cover.stl
    [artnetnode shell oled cover.stl]
2025-05-13 Rename artnetnode shell v10 shell.stl to 3D Print Files/artnetnode shell.stl
    [artnetnode shell.stl]
2025-06-10 Added V2 node shell with added screw-holes
    [artnetnode shell V2.stl]
2025-10-02 Updated 3D print stl files
    [Artnet ART top V1.stl, artnetnode oled v10.stl, artnetnode shell V2.stl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]
2025-12-18 Enhance network mode handling and boot buttonAdded boot button mode switch
    Refactor network setup to support multiple modes and add boot button functionality.
2025-12-26 Top cover with button
    Added button to top cover to reach the boot button for selecting modes and settings.
    [Artnet ART top V2 - boot.stl]
2025-12-29 Improve Ethernet status handling
    Improve Ethernet connection handling when reconnecting ethernet cable.
2025-12-29 Initialize LEDs to off before driver setup
    Added initialization code to set all LEDs to black before driver initialization.
2025-12-29 Synchronize Config and Bootbutton Mode settings
    Added logic to update and sync useWiFi flag in web config and Boot button.
2025-12-29 Implement standalone RGB Test and Static Color modes
    Added standalone modes for RGB Test and Static Color without network initialization. Updated network mode cycling to include these new modes through Boot button and adjusted settings accordingly.
2025-12-29 improve Static color selection, Change status led to static color.
    Added RGB extraction and status LED updates for color selection and static color modes.
2026-01-20 Small design changes
    Fitted top cover to new PCB design.
    [Artnet ART top V2 - boot.stl]
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2026-01-21 Added updated .Bin
    Added updated bin file with Boot button features.
2026-02-06 Added static-dhcp switch
    Long Boot button press functionality to switch between static ip and DHCP mode
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2026-02-07 Fixed channel and max leds for rgb and rgbw
2026-02-07 Latest build
    including RGBW support, Static IP switching via boot button, improved UI, and Dark mode.
2026-03-04 Create wled_cfg.json
    WLED config file with proper LED pin settings
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2026-05-03 Added APA102 support
    Added apa102 support. clock line on pin 17 on pin header. Only RGB for now.
2026-05-03 Enhance LED configuration with channel modes
    Updated LED configuration to support multiple channel modes including RGB, RGBW, and RGBWW. Adjusted related functions and UI elements to accommodate the new channel mode settings.
2026-05-06 Enhance README with LED types and corrections
    Updated LED support details and fixed typos in README.
2026-05-11 Improve LED data initialization and handling
    Refactor LED data handling for RGBWW and RGBW modes. Added buffer clearing to prevent rogue first LED colors.
2026-05-12 New update w/ RGBAW and SPI-based LED support!
    additional some bug fixes
2026-05-17 Implement fade mode for LED colors
    Added a new fade mode that smoothly transitions between random colors on all active channels. Updated settings and UI to enable this feature.
2026-05-22 New PCB enclosure design files
    [Artnet ART top V3 - boot.stl]
2026-05-25 Fixed wrong output order
    [Artnet ART top V3 - boot.stl]
2026-05-25 Adjusted mounting holes and clearance
    [artnetnode shell V2.stl]
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2026-07-16 Update README with ESP32 compatibility and pinout
    Added a note about ESP32 board compatibility and included a pinout image.
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2026-07-16 WLED Install for V3 boards + OLED
    custom wled install that enables light output by pulling down OE of the level shifter. Also added OLED usermod to support the oled screen!
2026-07-16 Config for V3 boards
    Also backwards compatible with older verison boards
2026-08-13 Implement group size handling for LED fixtures
    Added group size configuration and related functions for handling LED fixtures. Updated display function to accommodate grouped output for better performance.
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2026-10-28 Add firmware version and OLED screen rotation
    A FIRMWARE_VERSION define (with the compiler's build date) is shown as a
    sixth stop of the boot-button menu, "Firmware Info", and in the web page
    masthead and OTA page. The node rests on that screen until the next press
    wraps the menu round to Ethernet.
    A persisted screenRotation setting flips the OLED 180 degrees for nodes
    mounted upside-down. It is set once at boot and toggled from the Hardware
    section of the web page.
2026-10-28 Move W5500 sketch into an Arduino sketch folder with .ino extension
    The Arduino IDE requires a sketch to live in a folder of the same name with
    a .ino extension. webassets.h moves with it because the sketch includes it
    relative to its own directory.
2026-10-28 Firmware 1.1.0: stable output on a busy network
    - Show WS2812 frames with WAIT instead of NO_WAIT from the Art-Net
    callback. The driver's NO_WAIT path times out at the bare transfer time,
    so a frame arriving while the strips are still being clocked restarted
    the hardware early; the strips never latched and output collapsed to
    about 1 fps whenever the console ran faster than the transfer time.
    Grouped output no longer needs a second frame buffer.
    - Freeze LED output before the config handler rewrites settings, so the
    LED task cannot call a driver that only exists after the restart
    (crash when switching WS2812 to APA102).
    - Stop polling the network on a timer. The page polls on l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
2026-11-01 Firmware 1.1.1: amber activity flash on the status LED
    While frames are reaching the strips, the status LED adds a short amber
    flash twice a second on top of the steady green, so a glance shows whether
    the console is talking to the node. Green stays lit throughout; it settles
    back to steady green half a second after frames stop. Live DMX mode only.
